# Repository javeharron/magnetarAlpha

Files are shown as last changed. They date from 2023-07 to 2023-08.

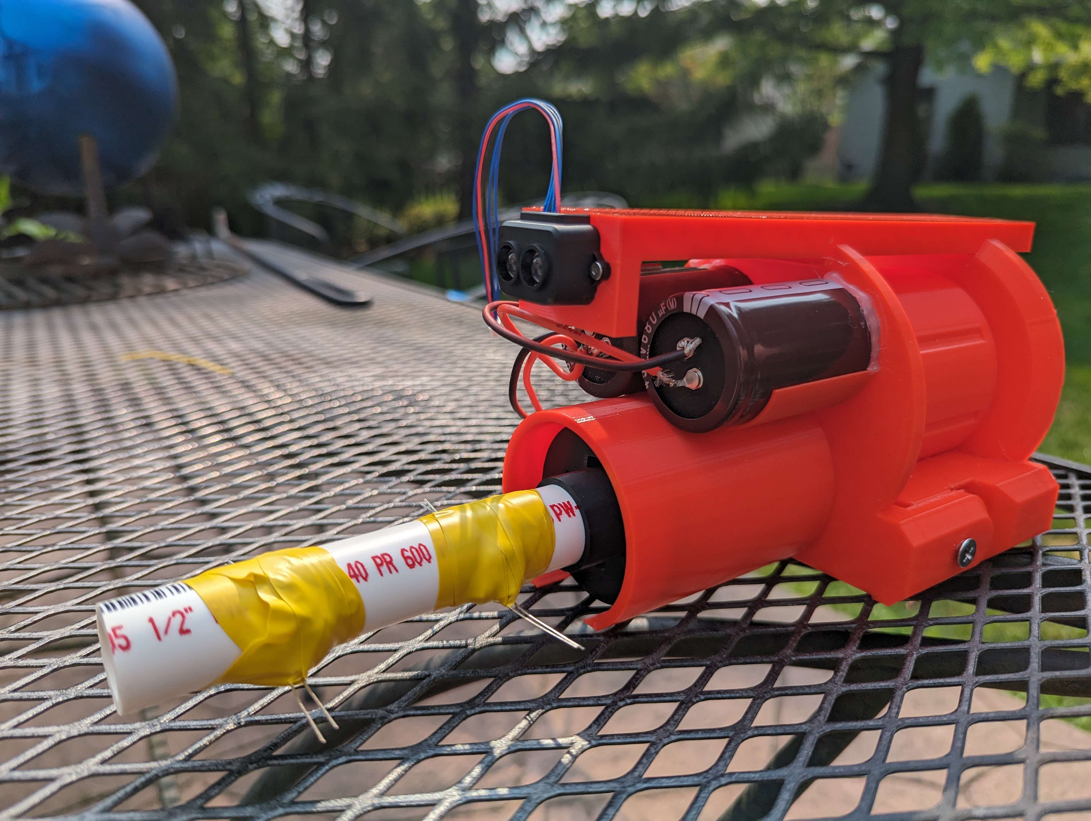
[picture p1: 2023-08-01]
Magnetar-Photos/Magnetar-Testing.jpg

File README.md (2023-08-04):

# Magnetar
Magnetar is a distance-ranging coil gun platform.

## Description
This system is designed to utilize commercially available LiDAR modules for distance-based energy correction. As a projectile from a coil gun flies through the air energy is lost through drag. The goal of this project was to create a model to correct for this loss so projectiles impact with consistent energy.

This system utilizes a simple revolving design to house multiple projectiles for subsequent firing. These projectiles are standard-length Nerf darts combined with a ferromagnetic insert (M4x12mm Bolt with bolt head against inner tip of dart). The coil used is 215 turns of 18 AWG enameled copper magnet wire. This is wrapped along a 45mm 3D-printed PLA shaft. To calculate the corrected velocity necessary to overcome drag energy losses an iterative equation is used. Essentially, out to a set amount of resolution drag losses are added to the projectile's target impact velocity. The target velocity is found using the kinetic energy formula or: 

# $`E_k = \frac{1}{2}mv^2`$

From this target velocity drag is added over set time intervals modeled by the equation: 

# $` V_i = V_t + \frac{\frac{1}{2}{\rho}V_t^2AC_d}{M}R`$

In this equation, $`V_i`$ is the initial velocity after a set time interval of inverse drag. $`V_t`$ is the initial/target velocity of the projectile and R is the resolution of the time interval (e.g. 0.001 for millisecond intervals). Per loop $`V_i`$ becomes the next $`V_t`$. This is continuously run until:
# $`V_it = d`$

Finally, the voltage necessary to achieve this velocity is calculated using the formula of: 
# $`V = \sqrt{\frac{\frac{1}{2}V_i^2}{C\frac{1}{2}E_c}}`$
where $`E_c`$ is the efficiency constant of the coil (e.g. 2.25% or 0.0225) for how much potential energy of the capacitors is converted to the kinetic energy of the projectile.

### Items
The Magnetar project files include the following: 
- Fully modular and customizable software.
- A modular data logging program and corresponding visual studio project files to intercept serial port communication for dumping into .XLSX formats.
- All 3D files in .STL format for additive manufacturing.
- Data from testing the system at various 1-meter distances.
- Full circuit schematic of the design.
- Flow charts for all code present.
- Sample BOM for at-home fabrication.

### Configurable features
Currently, the firmware allows for the configuration of:
- Pins for circuit control and HID.
- Capacitance of system.
- Efficiency constant of the coil.
- Mass of dart projectile.
- Cross-sectional area of the projectile.
- Density of environment.
- Maximum voltage for capacitors.
- Table output.
- Switching between full and auto-ranging power.
- Target energy.

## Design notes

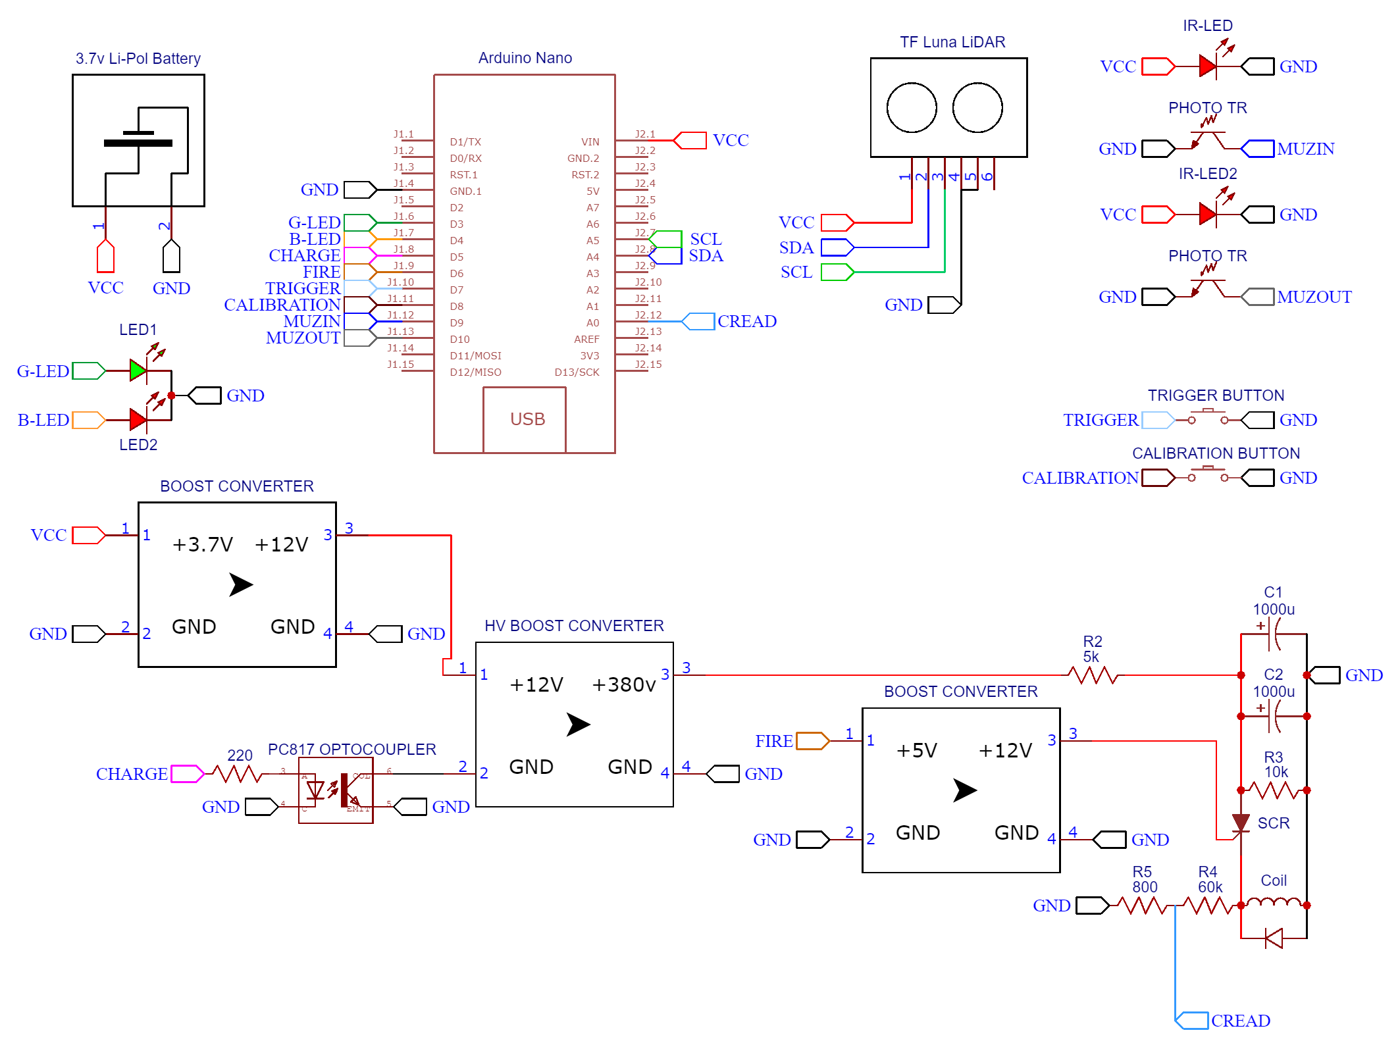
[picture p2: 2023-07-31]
Magnetar-Photos/Magnetar-Final Schematic.png

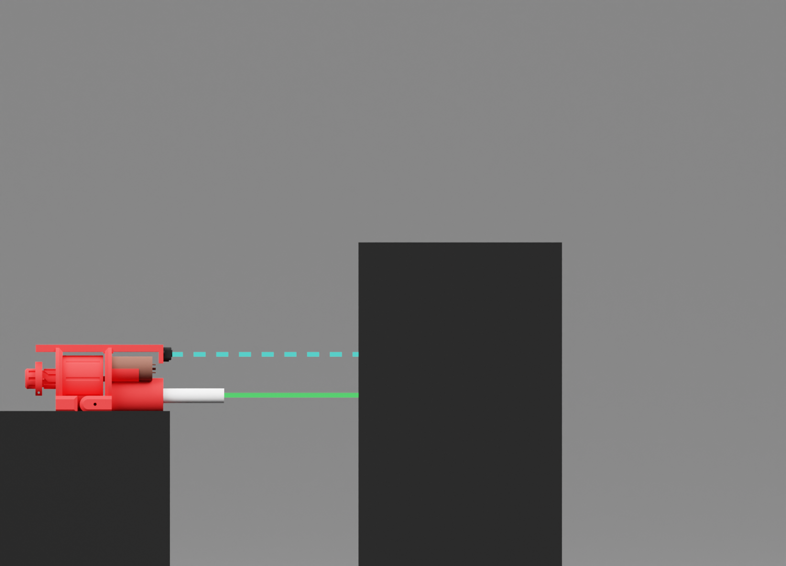
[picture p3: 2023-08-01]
Magnetar-Photos/Magnetar-Renders/Magnetar-FireShort.png

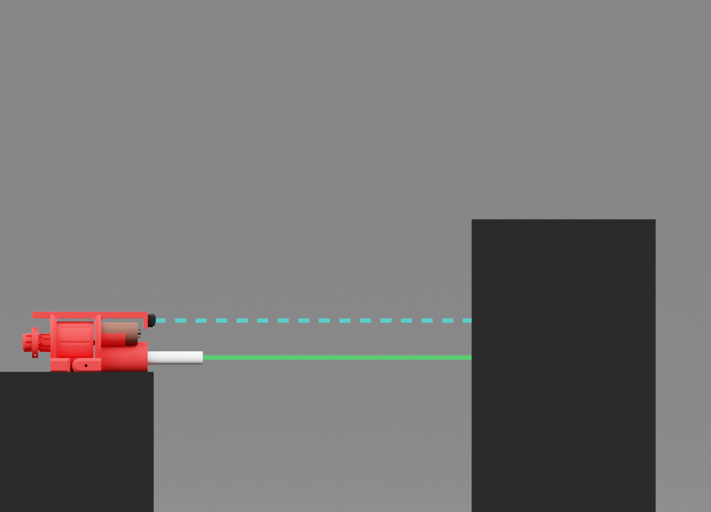
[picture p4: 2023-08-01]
Magnetar-Photos/Magnetar-Renders/Magnetar-FireLong.png

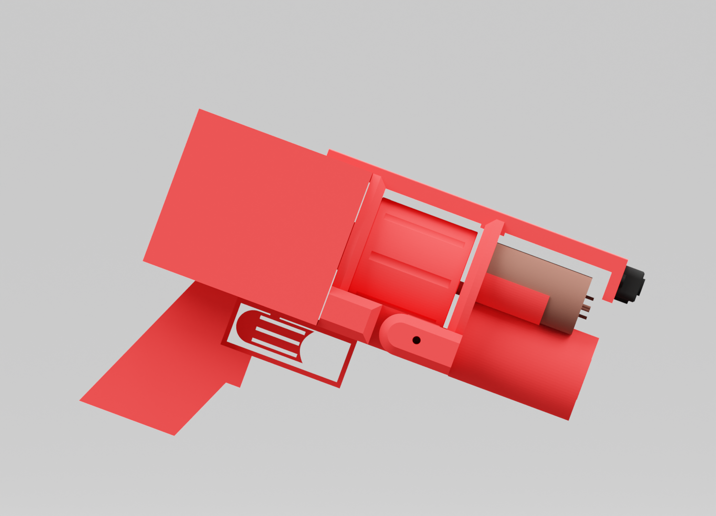
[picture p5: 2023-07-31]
Magnetar-Photos/Magnetar-Renders/Magnetar-Render.png

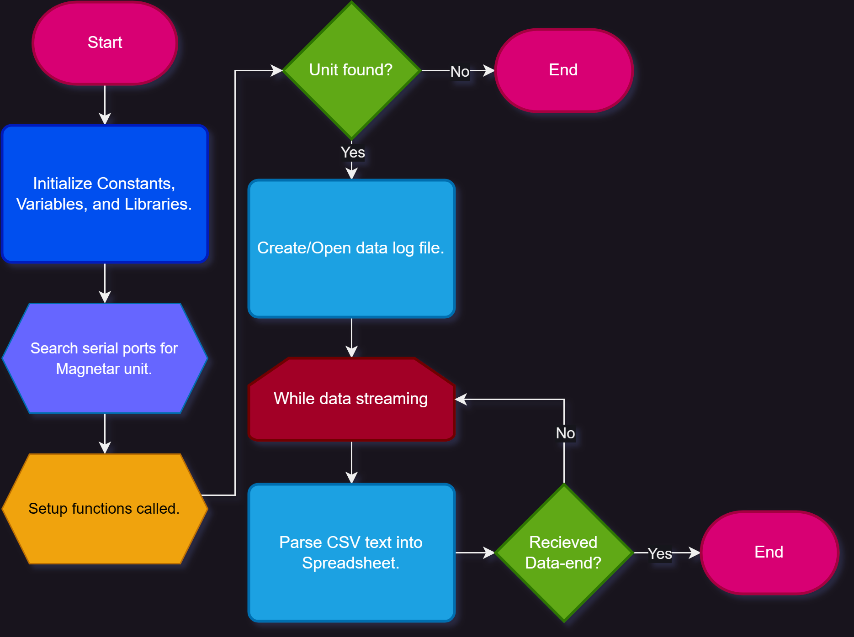
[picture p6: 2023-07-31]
Magnetar-Photos/Magnetar-DataLoggerFC.png

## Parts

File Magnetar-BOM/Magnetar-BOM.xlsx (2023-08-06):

Magnetar Example BOM
Item Name | Quantity | Cost Per Item | Total cost | Link
TF-Luna MicroLidar | 1 | $21.99 | $21.99 | Amazon (https://www.amazon.com/dp/B088NVX2L7?psc=1&ref=ppx_yo2ov_dt_b_product_details)
Atmega328p MCU | 1 | $11.99 | $11.99 | Amazon (https://www.amazon.com/KYBER-1x-Nano-ATMEGA328p-Type/dp/B0CCBY1SMS?s=electronics)
Ceramic Cement Resistors | 1 | $5.49 | $5.49 | Amazon (https://www.amazon.com/TOUHIA-Wirewound-Ceramic-Resistor-Inductionless/dp/B07VT23CR3)
18 AWG Enameled Copper Wire | 1 | $26.54 | $26.54 | Amazon (https://www.amazon.com/BNTECHGO-AWG-Magnet-Wire-Transformers/dp/B07GBNQ1DS?s=industrial)
3.7V Li-Pol Battery | 1 | $11.80 | $11.80 | Amazon (https://www.amazon.com/dp/B07BTTRCTT?psc=1&ref=ppx_yo2ov_dt_b_product_details)
450v 1000uf Capacitor | 2 | $9.99 | $9.99 | Amazon (https://www.amazon.com/Frequency-Aluminum-Electrolytic-Capacitor-35x60mm/dp/B08518N797)
IR Led & Phototransistor Set | 1 | $5.49 | $5.49 | Amazon (https://www.amazon.com/dp/B00M1PN5TK?psc=1&ref=ppx_yo2ov_dt_b_product_details)
MT3608 Boost Modules | 1 | $9.99 | $9.99 | Amazon (https://www.amazon.com/dp/B089JYBF25?psc=1&ref=ppx_yo2ov_dt_b_product_details)
PC817 Optocouplers | 1 | $7.99 | $7.99 | Amazon (https://www.amazon.com/BOJACK-PC817-OPTOCOUPLER-Installation-PC817C/dp/B08CXRHDHP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)
HV Boost Converter | 1 | $8.24 | $8.24 | Amazon (https://www.amazon.com/dp/B07SM89NJ4?psc=1&ref=ppx_yo2ov_dt_b_product_details)
HV SCR Thyristor | 1 | $9.56 | $9.56 | Amazon (https://www.amazon.com/dp/B088ZHY4SF?psc=1&ref=ppx_yo2ov_dt_b_product_details)
Assorted LEDs | 1 | $6.99 | $6.99 | Amazon (https://www.amazon.com/eBoot-Pieces-Emitting-Diodes-Assorted/dp/B06XPV4CSH?s=industrial)
Assorted Buttons | 1 | $6.99 | $6.99 | Amazon (https://www.amazon.com/Momentary-Pushbutton-Breadboard-Electronic-Electronics/dp/B09R42T3CB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)
Assorted Metric Bolts | 1 | $25.99 | $25.99 | Amazon (https://www.amazon.com/Assortment-M2-M3-M4-M5/dp/B0BX6HJQ3Z?sp_csd=d2lkZ2V0TmFtZT1zcF9hdGY)
ZURU X-Shot Excel Darts | 1 | $9.99 | $9.99 | Amazon (https://www.amazon.com/XShot-Darts-Refill-Universally-Compatible/dp/B0BS4FGVYY)
 |  |  | $0.00
Total Cost : |  |  | $179.03

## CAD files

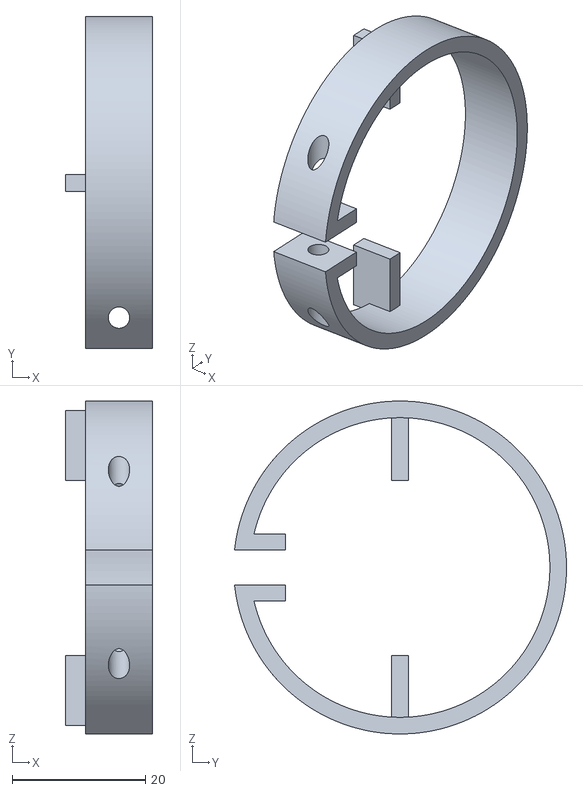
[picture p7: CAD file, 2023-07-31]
Magnetar-3DF/Magnetar - Follower.STL
13.0 x 49.9 x 50.0

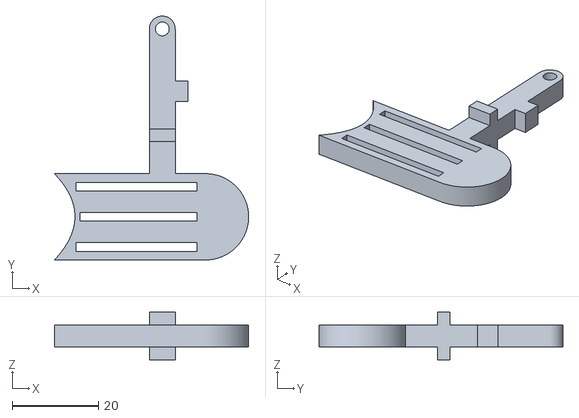
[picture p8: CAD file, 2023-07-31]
Magnetar-3DF/Magnetar - Trigger.STL
45.0 x 56.5 x 11.0

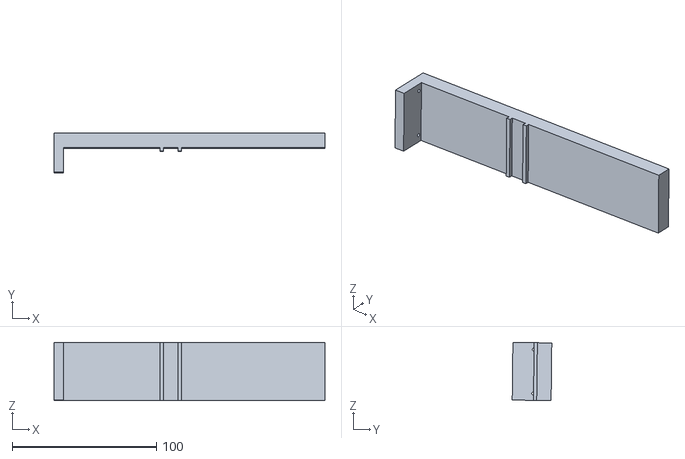
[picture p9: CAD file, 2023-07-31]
Magnetar-3DF/Magnetar - Rail.STL
188.0 x 27.5 x 40.3

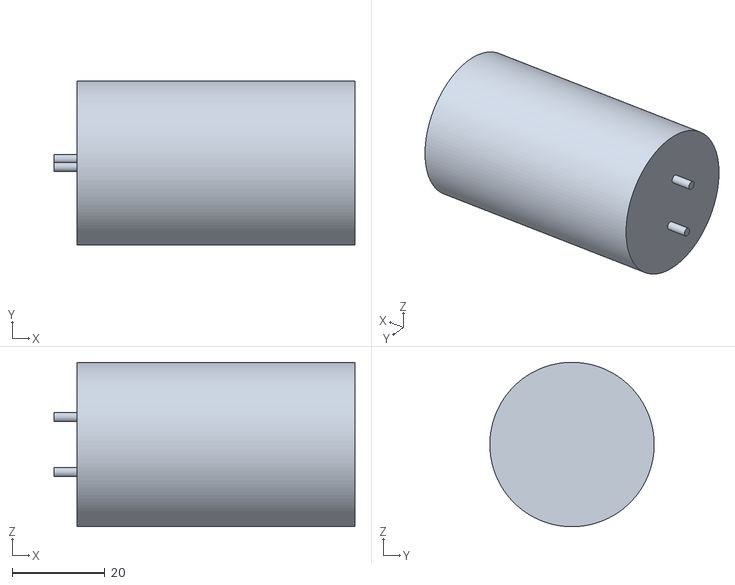
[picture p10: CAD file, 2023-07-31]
Magnetar-3DF/Magnetar - CapacitorFootprint.STL
65.0 x 35.5 x 35.5

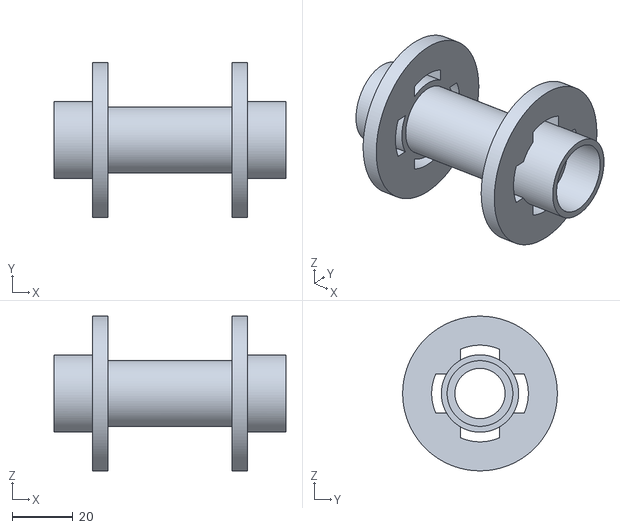
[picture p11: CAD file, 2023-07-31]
Magnetar-3DF/Magnetar - CoilBase.STL
76.2 x 50.8 x 50.8

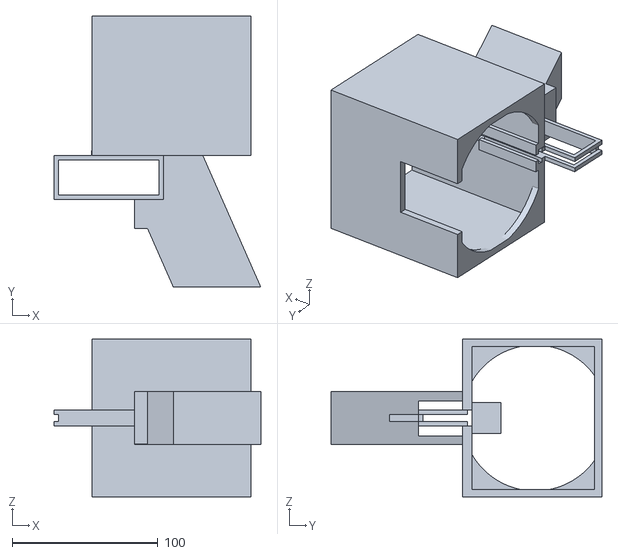
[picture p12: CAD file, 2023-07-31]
Magnetar-3DF/Magnetar - Handle.STL
141.7 x 185.8 x 108.3

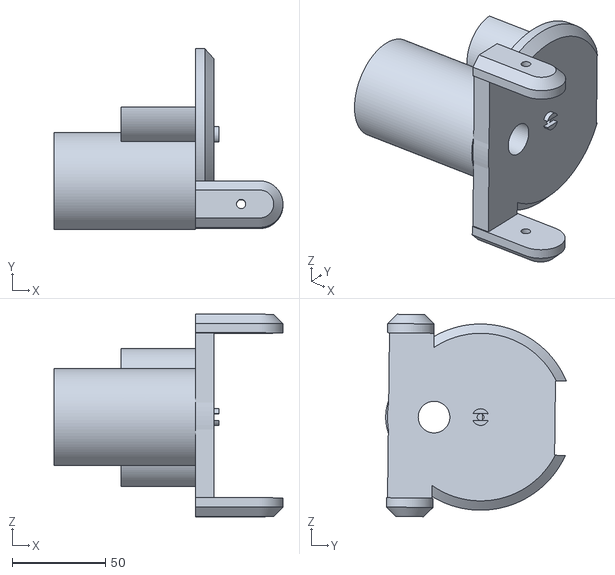
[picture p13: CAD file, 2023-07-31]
Magnetar-3DF/Magnetar - FrontDisk.STL
123.0 x 97.1 x 108.8

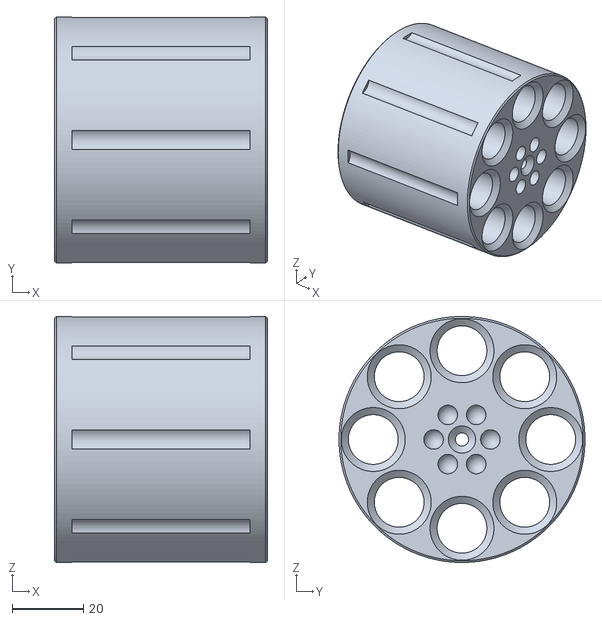
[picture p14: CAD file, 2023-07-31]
Magnetar-3DF/Magnetar - Cylinder.STL
60.0 x 69.3 x 69.3

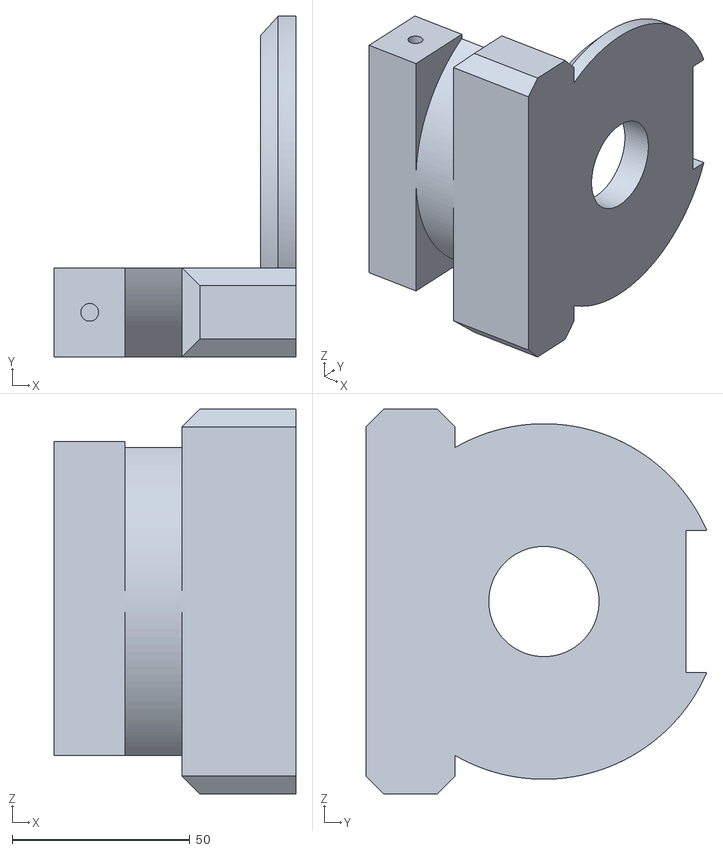
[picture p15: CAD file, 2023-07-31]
Magnetar-3DF/Magnetar - BackDisk.STL
68.0 x 95.8 x 108.3

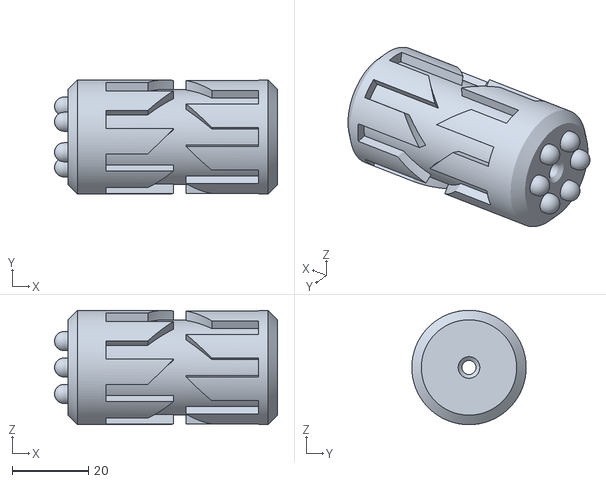
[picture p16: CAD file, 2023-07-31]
Magnetar-3DF/Magnetar - Cam.STL
58.5 x 30.0 x 30.0

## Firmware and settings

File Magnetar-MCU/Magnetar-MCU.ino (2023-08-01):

//Copyright (c) 2023, John Simonis and The Ohio State University
//This code was written by John Simonis for the Magnetar research project at The Ohio State University.

#include <Wire.h> //Standard wire library for I2C. 
#include <TFLI2C.h> //This is a library for the TF-Luna lidar module which is used in this project. https://github.com/budryerson/TFLuna-I2C

TFLI2C LidarSensor; //This initializes the TF-Luna lidar sensor using the I2C Lidar library.

int16_t LidDist; //This variable is used to store the Lidar distance data.
int Voltage, VoltageNec;
int CalibCnt = 0;

const int Capacitance = 0.0017483; //Capacitance in F.
const int TargetEnergy = 1; //In J
const int MaxVoltage = 380; //In V
const int MuzDist = 5; //In Cm;
const int16_t I2CAddress = 0x10;

const byte OkayLight = 3; //Digital pin for the Okay/green light.
const byte BadLight = 4; //Digital pin for the Bad/red light.
const byte ChargePin = 5; //Digital pin for controlling the charge cycle of the capacitor.
const byte FirePin = 6; //Digital pin for triggering the firing of the coil gun.
const byte TriggerPin = 7; //Digital pin for reading the trigger button value.
const byte CalibPin = 8; //Digital pin for calibrating coil gun.
const byte ReadPin = A0; //Analog pin for reading the voltage value on the capacitor bank.
const byte MuzIn = 9; //Digital pin for muzzle initial
const byte MuzFin = 10; //Digital pin for muzzle final
const bool Table = true;

float Dist,TOF,VelocityNec, Velocity; //Dynamic floating point numbers for distance, time of flight, and velocity.

const float DragCoef = 0.67; //Drag coefficient for air drag calculations.
const float Resolution = 0.001; //Resolution for air drag curve calculations.
const float Density = 1.225; //Density of air (SI units).
const float Area = 0.00011844; //Cross sectional area (m^2).
const float Mass = 0.01139; //Mass in kg.
const float Efficiency = 0.01; //% Efficiency of coil. 

bool Fired, FullPower;

float InverseDrag(float Distance){ //This function inverts normal air drag to ensure that a target travels at an initial velocity that degrades into a specified target velocity.
  float Ctr = 0; //Ctr for inverse drag function.
  float Temp = 0; //Temp value for TOF.
  float Veloc = sqrt(TargetEnergy/(Mass*0.5)); //Calculates ideal velocity from target energy.
  while(Temp<Distance){ //Iteratively calculates the starting velocity necessary to get to the distance at target energy.
      Veloc += ((0.5 * Density * pow(Veloc,2) * Area * DragCoef) / Mass * Resolution);
      Ctr += Resolution;
      Temp = Veloc * Ctr;
  }
  return Veloc;
}

float Drag(float Veloc, float TOF){ //This is the normal air drag function included for debug purposes and ballistic table generation.
  for (float i = 0; i <= TOF; i += Resolution) {
      Veloc -= ((0.5 * Density * pow(Veloc,2) * Area * DragCoef) / Mass * Resolution);
  }
  return Veloc;
}

float MuzVel() {
  if (!digitalRead(MuzIn)) {
    float CurrentMillis = millis();
    float TotalMillis;
    while (digitalRead(MuzFin)) {
      TotalMillis += (millis() - CurrentMillis);
    }
    return (MuzDist/100)/TotalMillis;
  }
}

int ReadVoltage(){ //Due to the amount of times voltage needs to be read this function is necessary.
  digitalWrite(ChargePin, 0);
  digitalWrite(OkayLight, 0);
  digitalWrite(FirePin, 0);
  return map(analogRead(A0), 0, 1023, 0, MaxVoltage);
}

void setup() {
  Serial.begin(115200); //Opens a serial communication line over 115200 baud for communication and debugging.

  pinMode(OkayLight, OUTPUT);//Configures all pins to necessary specifications.
  pinMode(BadLight, OUTPUT);
  pinMode(ChargePin, OUTPUT);
  pinMode(FirePin, OUTPUT);
  pinMode(TriggerPin, INPUT_PULLUP);
  pinMode(CalibPin, INPUT_PULLUP);
  pinMode(ReadPin, INPUT);
  pinMode(MuzIn, INPUT_PULLUP);
  pinMode(MuzFin, INPUT_PULLUP);

  Voltage = ReadVoltage(); //Reads the voltage across the capacitor bank.
  FullPower = false;

  while(Voltage > 0){ //Discharges the capacitors if there is any voltage before main loop can be run
    digitalWrite(BadLight, 1);
    delay(1000);
    digitalWrite(ChargePin,0);
    Voltage = ReadVoltage();
  }
}

void loop() {
  if(!digitalRead(CalibPin) && digitalRead(TriggerPin)){ //This is a seperate button for calibrating distance, because the lidar sensor is noisy this allows users to calibrate on a target at a specified distance for charging
    Voltage = ReadVoltage();
    LidarSensor.getData(LidDist,I2CAddress);
    Dist = LidDist/100; //Converts the distance from cm to m.
    VelocityNec = InverseDrag(Dist);
    VoltageNec = sqrt((0.5*pow(VelocityNec,2)*Mass)/(Capacitance*0.5*Efficiency)); //This is the amount of Voltage necessary to arrive at the target at the desired energy.
    CalibCnt++;
  }

  if(!digitalRead(CalibPin) && !digitalRead(TriggerPin)){
    FullPower = !FullPower;
  }

  if(CalibCnt > 0 && !FullPower){ //If the distance is calibrated we can start the charging process
    Voltage = ReadVoltage(); //Measure the current voltage for sanity.
    while((Voltage >= VoltageNec + 2 && Voltage <= VoltageNec - 2) && !FullPower){ //While we are outside the target voltage range charge the capacitors accordingly in 5ms pulses
      Fired = false;
      if(Voltage > VoltageNec + 2){
        digitalWrite(ChargePin,0);
        delay(5);
        Voltage = ReadVoltage();
      }
      else{
        digitalWrite(ChargePin,1);
        delay(5);
        Voltage = ReadVoltage();
      }
    }
    while((Voltage <= VoltageNec + 2 && Voltage >= VoltageNec - 2) &&!FullPower){ //While we are in the target voltage range alert the user and prepare to fire and recharge if necessary.
      digitalWrite(OkayLight, 1);
      if(!digitalRead(TriggerPin) && !Fired && digitalRead(CalibPin)){
        digitalWrite(FirePin,1);
        delay(5);
        digitalWrite(FirePin,0);
        Velocity = MuzVel();
        if(Table){
          Serial.println("Dist, Voltage, VoltageNec, Velocity, VelocityNec, Efficiency, Mass, Capacitance, CalculatedPE, CalculatedKE, Chronograph, ActualKE");
          Serial.println(String(Dist) + "," + String(Voltage) + "," + String(VoltageNec)) + "," + String(VelocityNec) + "," + String(Efficiency) + "," + String(Mass) + "," + String(Capacitance) + "," + String(0.5*Capacitance*pow(Voltage,2)) + "," + String(0.5*Mass*pow(Drag(Velocity,Dist/Velocity),2));
        }
      }
      else{
        Voltage = ReadVoltage();
      }
    }
  }

  if(FullPower){ //This is a check to determine if fullpower mode is engaged
      if(Voltage >= MaxVoltage - 5){
        digitalWrite(OkayLight, 1);
      }
      else{
        digitalWrite(BadLight, 1);
      }
      if(!digitalRead(TriggerPin) && !Fired && digitalRead(CalibPin) && Voltage >= MaxVoltage - 5){
        digitalWrite(FirePin,1);
        delay(5);
        digitalWrite(FirePin,0);
        Velocity = MuzVel();
        if(Table){
          Serial.println("Dist, Voltage, VoltageNec, Velocity, VelocityNec, Efficiency, Mass, Capacitance, CalculatedPE, CalculatedKE, Chronograph, ActualKE");
          Serial.println(String(Dist) + "," + String(Voltage) + "," + String(VoltageNec)) + "," + String(VelocityNec) + "," + String(Efficiency) + "," + String(Mass) + "," + String(Capacitance) + "," + String(0.5*Capacitance*pow(Voltage,2)) + "," + String(0.5*Mass*pow(Drag(Velocity,Dist/Velocity),2));
        }
      }
      else{
        Voltage = ReadVoltage();
      }
  }
}

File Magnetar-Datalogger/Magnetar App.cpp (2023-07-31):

//Copyright (c) 2023, John Simonis and The Ohio State University
//This code was written by John Simonis for the Magnetar research project at The Ohio State University.
#include <iostream>
#include <string>
#include <vector>
#include <thread>
#include <chrono>
#include <ctime>
using namespace std;

#include <serialib.h> //Simple serial port library https://github.com/imabot2/serialib

#include <OpenXLSX.hpp> //Simple XLSX library https://github.com/troldal/OpenXLSX
using namespace OpenXLSX;

char SERIAL_PORT[12] = "\\\\.\\COM"; //This is a character array/string that represents our COM port
string Columns[6] = {"A", "B", "C", "D", "E"}; //Here we have all of the column letters represented as a string due to OpenXLSX requirements
string Delimiter = ","; //This is what seperates each of our columns in the rows of text (CSV formatting)
string InpFN; //This is declared for filename input
char Cell[10]; //Simple cell buffer

const string currentDateTime() { //This is a function that fetches the current date and time using the ctime library
    time_t     now = time(0);
    struct tm  tstruct;
    char       buf[80];
    localtime_s(&tstruct, &now);
    strftime(buf, sizeof(buf), "%Y-%m-%d @ %X", &tstruct);

    return buf;
}

int main()
{
    vector<string> Data; //This vector stores all of our raw CSV data
    serialib serial; //Serial port object
    XLDocument doc; //Workbook object


    for (int i = 1; i < 99; i++) { //This iterates through all serial ports until it finds the one with a baudrate of 57600 which is specific to Magnetar
        SERIAL_PORT[7] = to_string(i)[0];
        SERIAL_PORT[8] = to_string(i)[1];
        if (serial.openDevice(SERIAL_PORT, 115200) == 1) { //This baudrate is relatively nonstandard so this shouldnt interfere with other serial devices
            cout << "Magnetar likely located on: " << SERIAL_PORT << endl;
            serial.closeDevice();
            break;
        }
    }

    char errorOpening = serial.openDevice(SERIAL_PORT, 57600); //Attempt to open the port on the first 57600 device

    if (errorOpening != 1) { 
        cout << "Error connecting to Magnetar. Close all other Serial COM apps!" << endl << "Press enter to exit."; 
        getchar(); 
        return 0; 
    }
    cout << "Successful connection to: " << SERIAL_PORT << endl << "Input XLSX File Name: "; //Outputs the proper com port.
    getline(cin, InpFN);
    try { doc.open(InpFN + ".XLSX"); } //Attempt to open the XLSX file if it already exists
    catch (exception) { doc.create(InpFN + ".XLSX"); } //Create it if it doesnt
    auto wks = doc.workbook().worksheet("Sheet1"); //Sets our scope to sheet1


    char buffer[20];

    cout << endl << "Written by John Simonis" << endl << "Copyright(C) 2023" << endl << "Magnetar (The Ohio State University)";

    this_thread::sleep_for(1.5s);//Normally pauses like this are bad practice, this is just to show the attributation.
 
    serial.writeString("SendData");//Sends the "SendData" string over serial to begin the table process

    while(true) { //This will continue logging data to our vector until we reach a DataEND or the user closes the program.
        serial.readString(buffer, '\n', 100);
        cout << buffer;
        if (strstr(buffer,"DataEND")){
            break;
        }
        else {
            Data.push_back(buffer); //This is somewhat bad practice as the program could theoretically overrun with data, this works for Magnetar table mode ONLY
        }
    }

    int counter = 0; //Here we store our counter and column counter in scope since we need to do a handful of operations
    int column = 0;
    size_t stringpos = 0;
    while (counter < Data.size()) {//This double while loop may look complicated but it is just parsing the string by its delimiter.
        while ((stringpos = Data[counter].find(Delimiter)) != string::npos) {//Also, it is attempting an int conversion on all strings so numerical data is represented properly.
            try { wks.cell(Columns[column] + to_string(counter + 1)).value() = int(stoi(Data[counter].substr(0, stringpos))); }
            catch(exception){ wks.cell(Columns[column] + to_string(counter + 1)).value() = Data[counter].substr(0, stringpos); }
                Data[counter].erase(0, stringpos + Delimiter.length());//Every time we remove a Delimited string we erase it from the original string
                column++;
        }
        try { wks.cell(Columns[column] + to_string(counter + 1)).value() = int(stoi(Data[counter])); } //This is outside the secondary while loop as it only triggers once there are no remaining Delimiters.
        catch(exception){ wks.cell(Columns[column] + to_string(counter + 1)).value() = Data[counter]; }
        column = 0;
        stringpos = 0;
        counter++;
    }

    wks.cell("G1").value() = "Last Run:"; //Here is where we use our date and time from the initial run of the program
    wks.cell("H1").value() = currentDateTime();
    
    doc.save();

    serial.closeDevice();

    cout << "Press enter to exit.";
    getchar(); //This is just an easy way to close the program through prompt, technically this is unecessary as the program would otherwise finish automatically.
    return 0;
}

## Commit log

2023-07-31 Update Magnetar App.cpp
2023-09-09 Add files via upload
    Updated PCBs
